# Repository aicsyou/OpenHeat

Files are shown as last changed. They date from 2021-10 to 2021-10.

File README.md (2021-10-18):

# OpenHeat：开源智能加热台
* 基于[peng-zhihui](https://github.com/peng-zhihui)的[OpenHeat](https://github.com/peng-zhihui/OpenHeat)， 调整了元器件的封装，方便手工焊接
* 项目设计使用KiCAD软件
* 固件不完全兼容（未完成）
* 注意： PCBA测试中
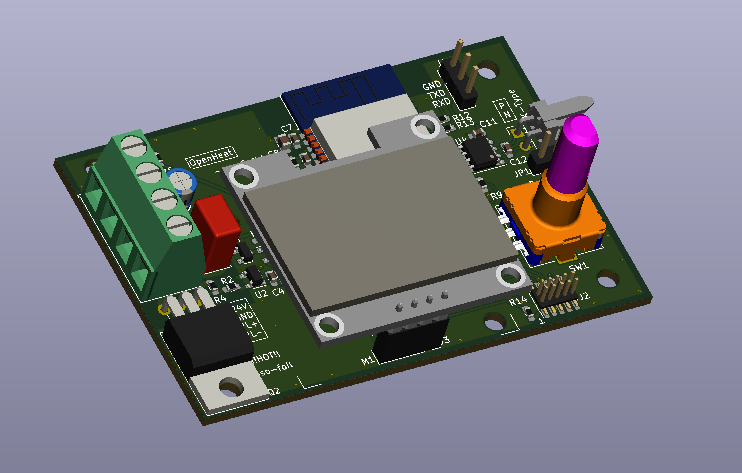
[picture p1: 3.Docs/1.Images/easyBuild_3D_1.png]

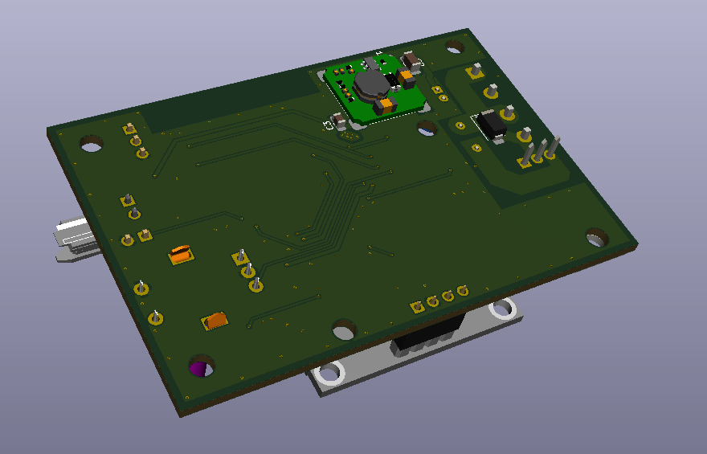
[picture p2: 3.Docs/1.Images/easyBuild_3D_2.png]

---------------------------------------------------------------------------

> 用于PCB回流焊的实用加热台，比较炫酷，可能目前市面上 **颜值最高** & **功能最强** 的加热台。

**参数：** 硬件方面基于`ESP32PICO-D4`芯片，输入电源`24V/10A`，最大功率200W，加热温度最高300℃；带蓝牙功能，***后续有空的话我会开发手机APP用于设置升温曲线*** 。

## 21-9-17 修复说明：



---

## 关于本项目



* 本项目参考了 [createskyblue](https://gitee.com/createskyblue) / [OpenT12](https://gitee.com/createskyblue/OpenT12)开源T12电烙铁项目的固件，感谢这位同学设计的优秀交互动画体验，UI设计深得我心哈哈~

* 另外铝基板热床的设计采用了[MRobot-Origin](https://github.com/MRobot-Origin)/ [GS_Hbed](https://github.com/MRobot-Origin/GS_Hbed)同学的分型曲线设计，非常有创意~

## 使用说明

#### 1. 打样说明

直接用Hardware文件夹里的Gerber文件打样即可：主控制器为4层PCB，无特殊工艺要求；热床为铝基板PCB，可以在嘉立创打样。

> 铝基板是一种专门用来散热的PCB板材，大家看到的很多大功率LED灯珠就是这种，前阵子嘉立创开放了铝基板打样业务，还很便宜。所以相比于设计一个金属块做热床，这种方式不但成本低而且美观实用。

另外其实还有一块可选两层板作为固定件的，这个我还没来得及设计，也很简单，大家可以根据自己情况画一个，或者直接3D打印结构件固定也行。

#### 2. 固件说明

固件我这边是基于PlatformIO移植的，所以大家用这个平台的话直接打开下载就行了；如果是用Arduino IDE的话，先安装Library里面的库文件，然后一样下载。

固件库没有完全配置完成（因为原版固件是设计为电烙铁使用的），晚些我硬件都就位了会调试好固件供大家直接下载。

#### 3. 关于结构件

这个我也还在设计，我的风格肯定是以美观小巧为主，大家可以等我放出3D打印文件。

#### 4. 关于温度传感器

我这边是用的是K型热电偶，在PCB上已经集成了采集芯片，需要自己买一个表贴式的K型热电偶连接到板子下方的两个焊盘。

> 注意热电偶和热床的接触要绝缘，用高温胶带隔一下就行。另外热电偶是有极性的，如果发现加热后温度反而下降说明接反了。
>
> 现在代码中还没有加热电偶的代码，晚一点有空了会调好完整固件。大家自己添加也很容易，MAX6675使用SPI驱动，Arduino平台有很多例程。

#### 5. 关于元器件BOM

**注意！！！** C9电容一定要选耐压足够的，因为是并联到24V的VCC上，如果耐压不够短路的话可以看到烟花！！

#### 接线图



## 欢迎star支持 :D









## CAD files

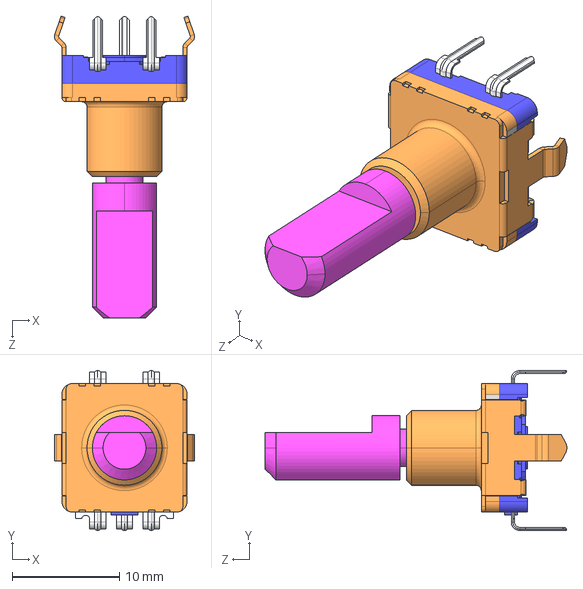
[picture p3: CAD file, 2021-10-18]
1.Hardware/OpenHeat/3d/EC11E-05SW.STEP
13.1 x 15.0 x 28.2 mm

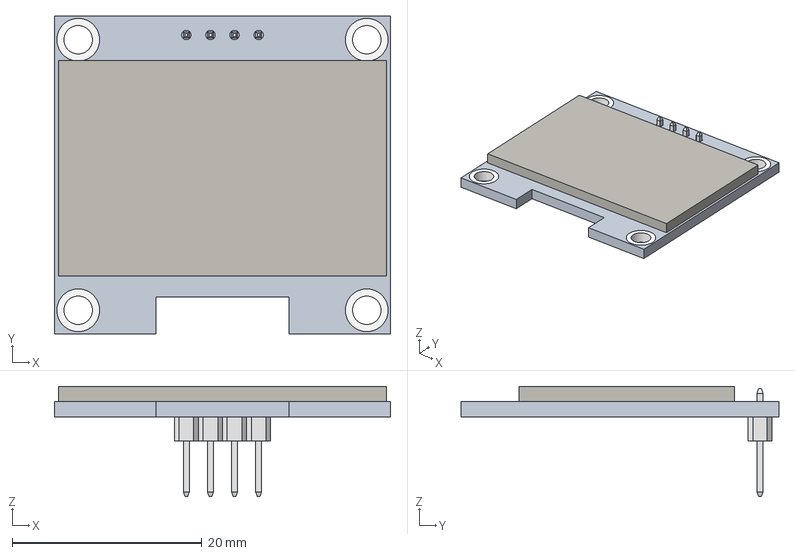
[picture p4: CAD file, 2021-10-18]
1.Hardware/OpenHeat/3d/Geekcreit 1.3 Inch 4Pin.step
35.4 x 33.5 x 11.6 mm
2.54mm_pin_header x 4

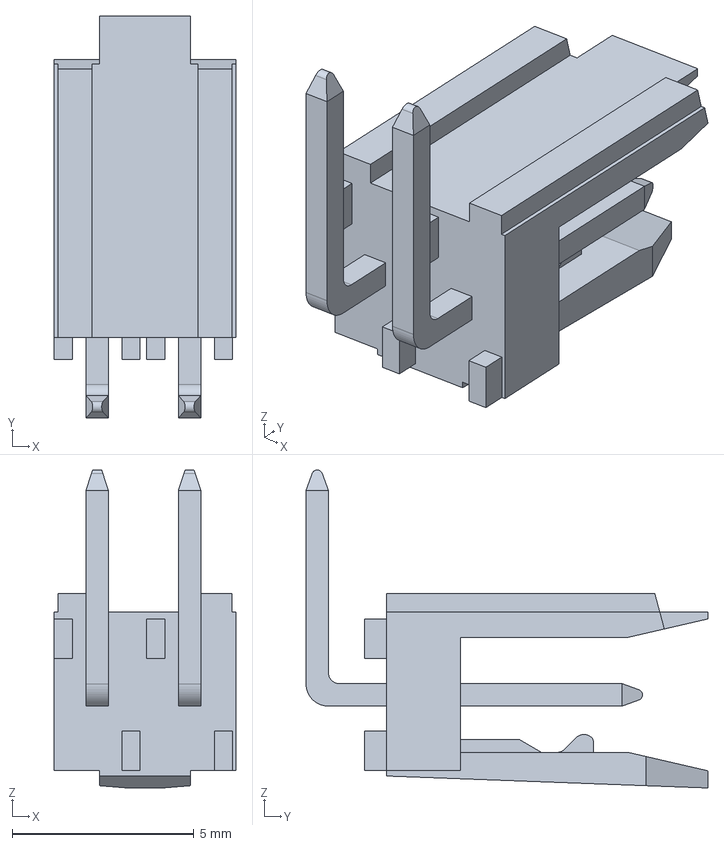
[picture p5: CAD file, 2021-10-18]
1.Hardware/OpenHeat/3d/76382-302LFc.stp
4.99 x 11.0 x 8.74 mm

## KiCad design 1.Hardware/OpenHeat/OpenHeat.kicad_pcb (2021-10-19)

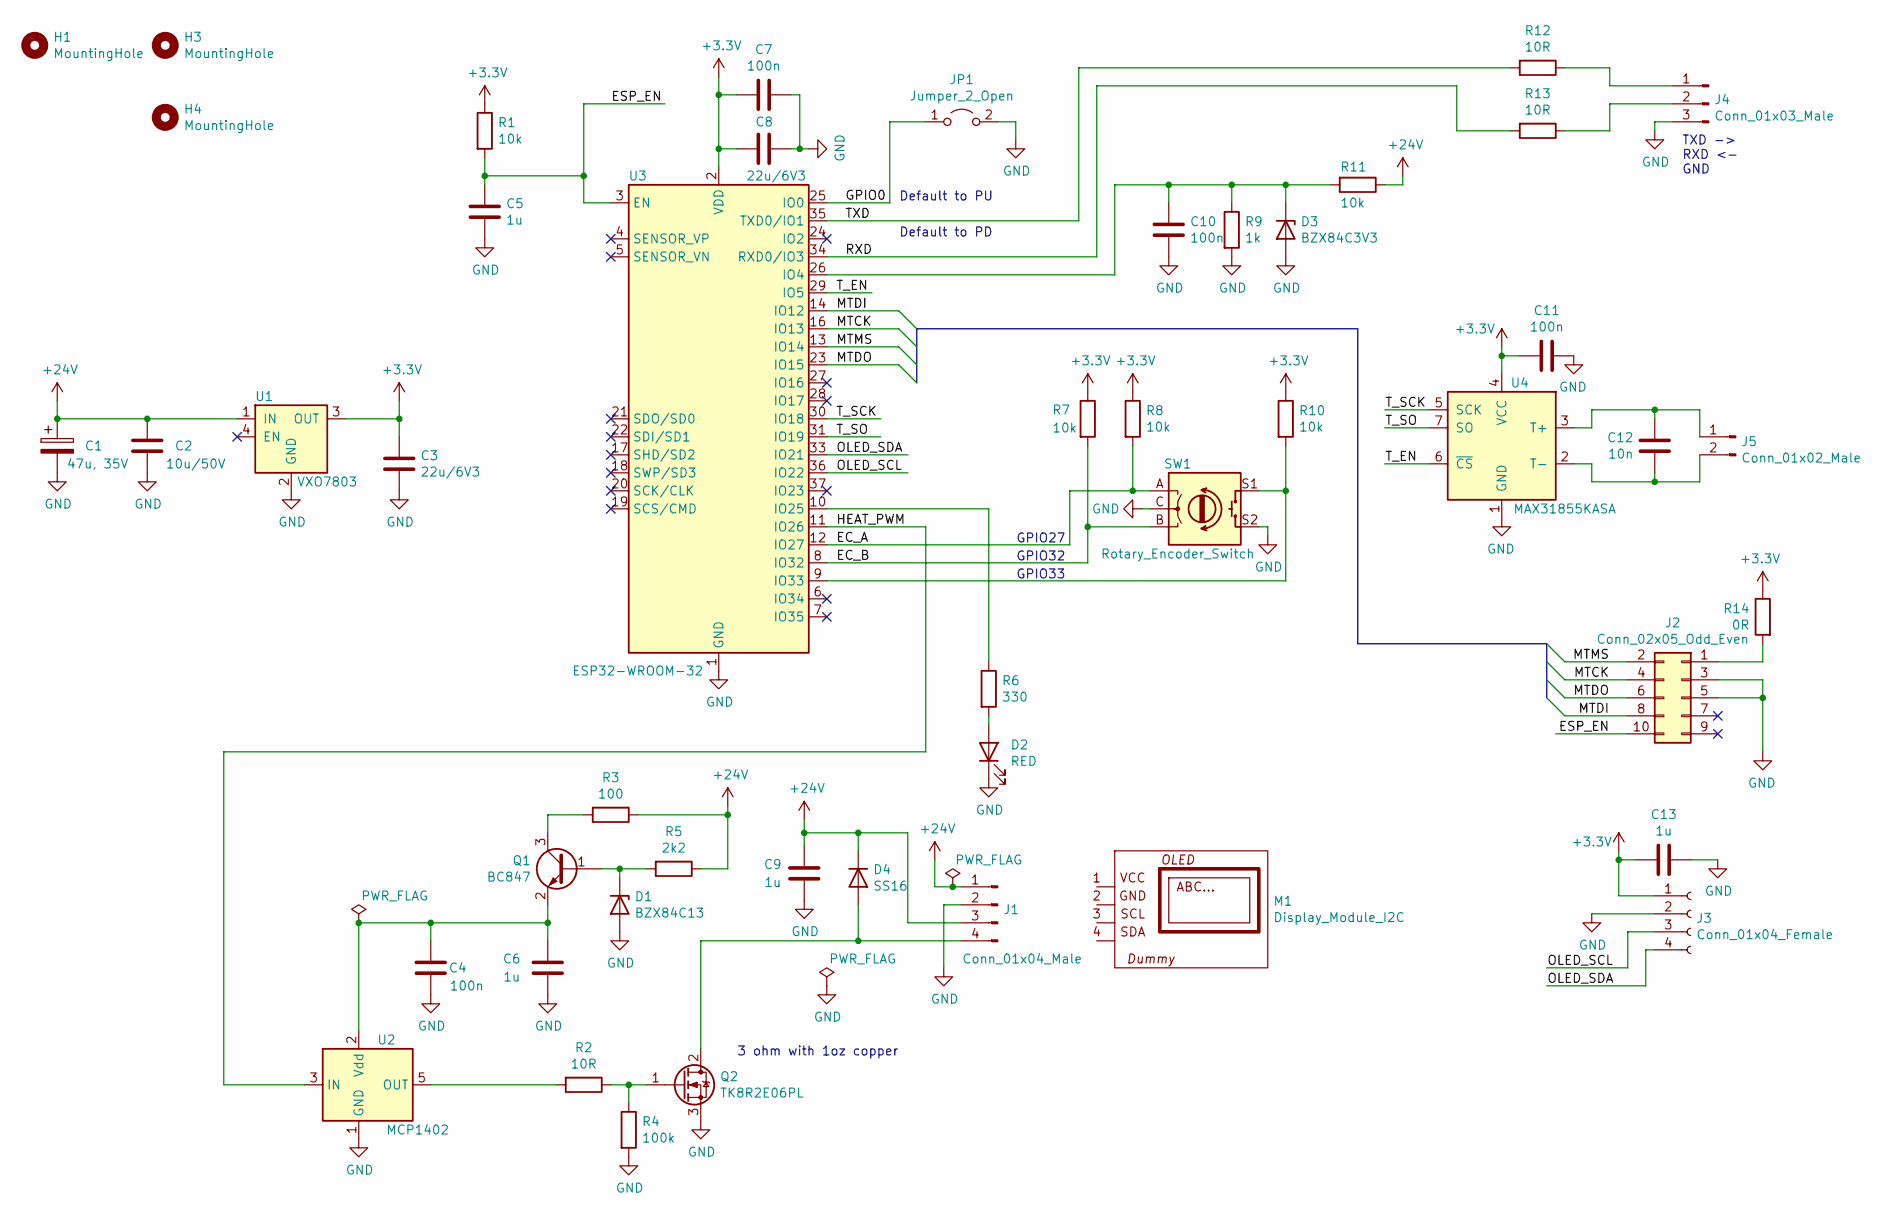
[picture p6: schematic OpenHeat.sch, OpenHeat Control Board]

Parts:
C1: 47u, 35V; CP_Radial_D5.0mm_P2.00mm; PartNo 860020472006
C2: 10u/50V; C_1206_3216Metric_Pad1.33x1.80mm_HandSolder
C3, C8: 22u/6V3; C_0805_2012Metric_Pad1.18x1.45mm_HandSolder
C4, C7, C10, C11: 100n; C_0603_1608Metric_Pad1.08x0.95mm_HandSolder
C5, C6, C13: 1u; C_0603_1608Metric_Pad1.08x0.95mm_HandSolder
C9: 1u; C_Rect_L7.2mm_W4.5mm_P5.00mm_FKS2_FKP2_MKS2_MKP2; PartNo B32529C105J
C12: 10n; C_0603_1608Metric_Pad1.08x0.95mm_HandSolder
D1: BZX84C13; D_SOT-23_ANK
D2: RED; LED_0805_2012Metric_Pad1.15x1.40mm_HandSolder
D3: BZX84C3V3; D_SOT-23_ANK
D4: SS16; D_SMA; PartNo SS16_R1_00001
H1, H3, H4: MountingHole; MountingHole_3.2mm_M3
J1: Conn_01x04_Male; TerminalBlock_Phoenix_MKDS-1,5-4-5.08_1x04_P5.08mm_Horizont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
J2: Conn_02x05_Odd_Even; PinHeader_2x05_P1.27mm_Vertical_SMD
J3: Conn_01x04_Female; PinSocket_1x04_P2.54mm_Vertical
J4: Conn_01x03_Male; PinHeader_1x03_P2.54mm_Vertical
J5: Conn_01x02_Male; PinHeader_1x02_P2.54mm_Horizontal
JP1: Jumper_2_Open; PinHeader_1x02_P2.54mm_Vertical
M1: Display_Module_I2C; OLED_128x64_096_I2C
Q1: BC847; SOT-23
Q2: TK8R2E06PL; TO-220-3_Horizontal_TabDown
R1, R7, R8, R10, R11: 10k; R_0603_1608Metric_Pad0.98x0.95mm_HandSolder
R2, R12, R13: 10R; R_0603_1608Metric_Pad0.98x0.95mm_HandSolder
R3: 100; R_0805_2012Metric_Pad1.20x1.40mm_HandSolder
R4: 100k; R_0603_1608Metric_Pad0.98x0.95mm_HandSolder
R5: 2k2; R_0603_1608Metric_Pad0.98x0.95mm_HandSolder
R6: 330; R_0603_1608Metric_Pad0.98x0.95mm_HandSolder
R9: 1k; R_0603_1608Metric_Pad0.98x0.95mm_HandSolder
R14: 0R; R_0603_1608Metric_Pad0.98x0.95mm_HandSolder
SW1: Rotary_Encoder_Switch; RotaryEncoder_Alps_EC11E-Switch_Vertical_H20mm
U1: VXO7803; VXO78-500-M; PartNo VXO7803-500-M-TR
U2: MCP1402; SOT-23-5
U3: ESP32-WROOM-32
U4: MAX31855KASA; SOIC-8_3.9x4.9mm_P1.27mm

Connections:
+3V3: C3.1, C7.1, C8.2, C11.1, C13.2, J3.1, R1.1, R7.1, R8.1, R10.1, R14.1, U1.3 (OUT), U3.2 (VDD), U4.4 (VCC)
+24V: C1.1, C2.1, C9.2, D4.1 (K), J1.1, J1.3, R3.1, R5.1, R11.1, U1.1 (IN)
/EC_A: R8.2, SW1.A, U3.12 (IO27)
/EC_B: R7.2, SW1.B, U3.8 (IO32)
/ESP_EN: C5.1, J2.10, R1.2, U3.3 (EN)
/GPIO0: JP1.1 (A), U3.25 (IO0)
/HEAT_PWM: U2.3 (IN), U3.11 (IO26)
/MTCK: J2.4, U3.16 (IO13)
/MTDI: J2.8, U3.14 (IO12)
/MTDO: J2.6, U3.23 (IO15)
/MTMS: J2.2, U3.13 (IO14)
/OLED_SCL: J3.3, U3.36 (IO22)
/OLED_SDA: J3.4, U3.33 (IO21)
/RXD: R13.2, U3.34 (RXD0/IO3)
/TXD: R12.2, U3.35 (TXD0/IO1)
/T_EN: U3.29 (IO5), U4.6 (~CS~)
/T_SCK: U3.30 (IO18), U4.5 (SCK)
/T_SO: U3.31 (IO19), U4.7 (SO)
GND: C1.2, C2.2, C3.2, C4.2, C5.2, C6.2, C7.2, C8.1, C9.1, C10.2, C11.2, C13.1, D1.2 (A), D2.1 (K), D3.2 (A), J1.2, J2.3, J2.5, J3.2, J4.3, JP1.2 (B), Q2.3 (S), R4.2, R9.2, SW1.C, SW1.S2, U1.2 (GND), U2.1 (GND), U2.4 (GND), U3.1 (GND), U3.15 (GND), U3.38 (GND), U3.39 (GND), U4.1 (GND)
unnamed: C4.1, C6.1, Q1.2 (E), U2.2 (Vdd)
unnamed: C10.1, D3.1 (K), R9.1, R11.2, U3.26 (IO4)
unnamed: C12.1, J5.2, U4.2 (T-)
unnamed: C12.2, J5.1, U4.3 (T+)
unnamed: D1.1 (K), Q1.1 (B), R5.2
unnamed: D2.2 (A), R6.2
unnamed: D4.2 (A), J1.4, Q2.2 (D)
unnamed: J2.1, R14.2
unnamed: J4.1, R12.1
unnamed: J4.2, R13.1
unnamed: Q1.3 (C), R3.2
unnamed: Q2.1 (G), R2.1, R4.1
unnamed: R2.2, U2.5 (OUT)
unnamed: R6.1, U3.10 (IO25)
unnamed: R10.2, SW1.S1, U3.9 (IO33)

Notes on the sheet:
Default to PD
Default to PU
GPIO32
GPIO27
GPIO33
3 ohm with 1oz copper
TXD -> RXD <- GND

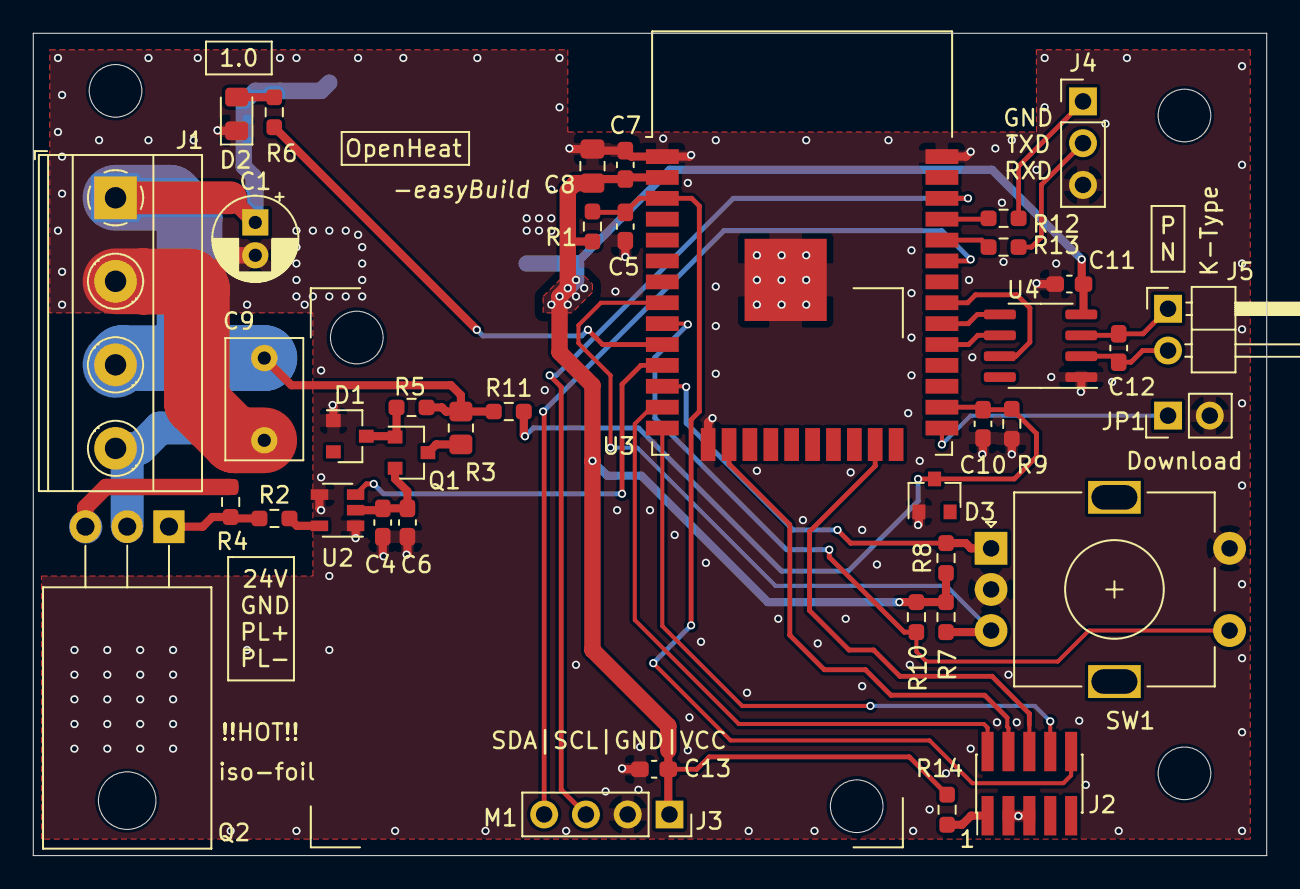
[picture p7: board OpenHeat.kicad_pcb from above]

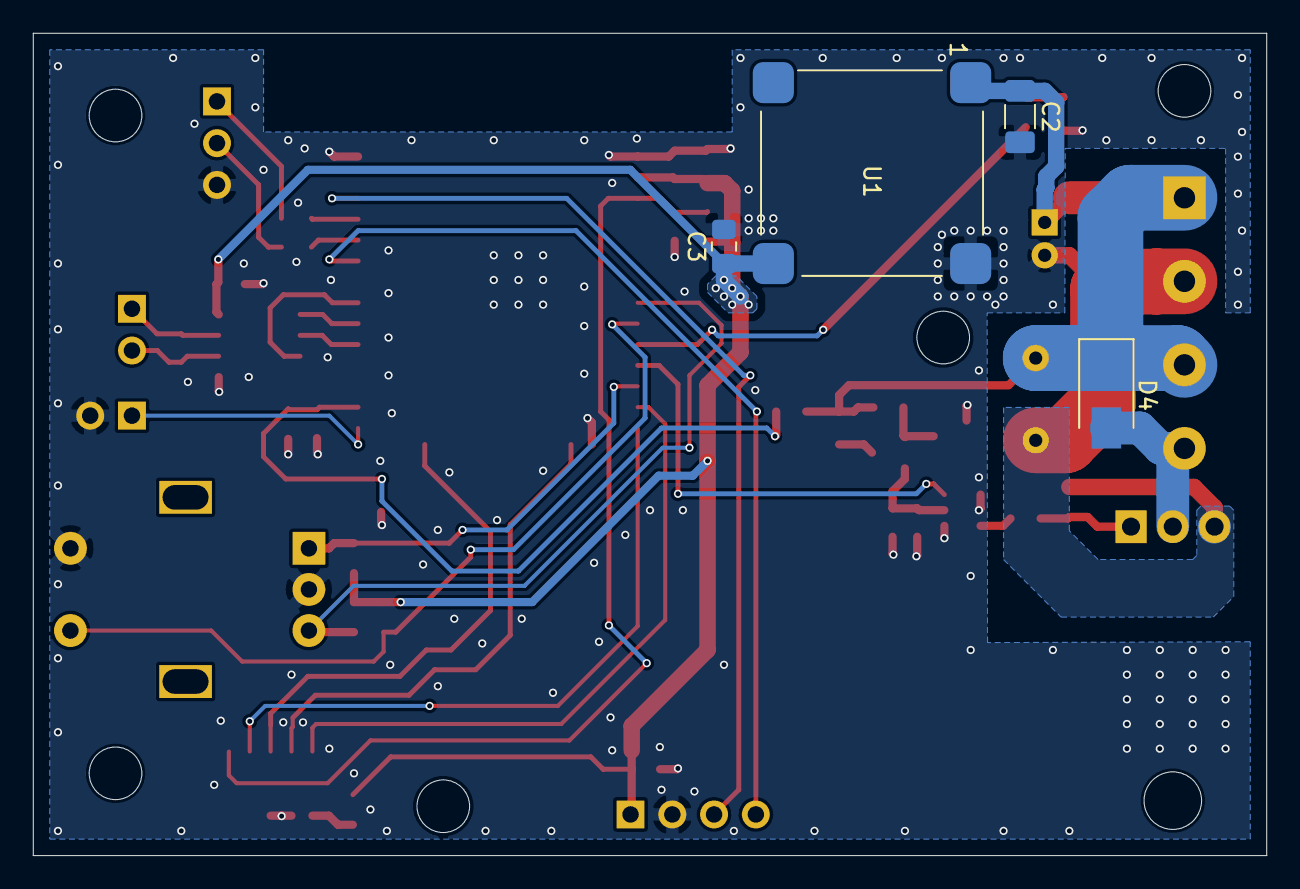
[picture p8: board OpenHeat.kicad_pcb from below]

Board: 2 copper layers, 75.0 x 50.0 mm, 48 parts (4 on the bottom side), 34 nets.

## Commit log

2021-10-18 KiCAD project
    Controller modified for easier build, project created with KiCAD
    [76382-302LFc.stp, EC11E-05SW.STEP, Geekcreit 1.3 Inch 4Pin.step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]
2021-10-19 Update OpenHeat.kicad_pcb
    Additional VIAs added
    [OpenHeat.kicad_pcb]
2021-10-19 Add manufacturing data for controller PCB
    Gerber files and drill files
    [OpenHeat-B_Cu.gbr, OpenHeat-B_Mask.gbr, OpenHeat-B_Paste.gbr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]
